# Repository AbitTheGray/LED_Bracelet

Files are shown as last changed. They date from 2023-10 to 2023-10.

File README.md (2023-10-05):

# LED Bracelet

Single-cell LED Bracelet controlled by ESP32-C3.

While the bracelet/collar can work in "standalone" mode, it is recommended to connect it to other device using [BLE](https://en.wikipedia.org/wiki/Bluetooth_Low_Energy).

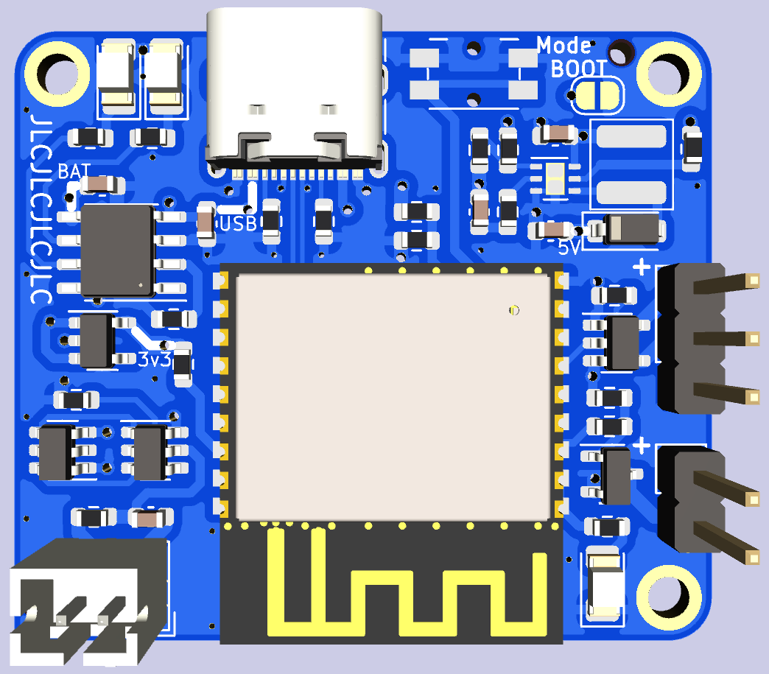
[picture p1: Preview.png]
PCB Preview


**This board is untested.**

Designed to be manufactured by [JLCPCB](https://jlcpcb.com/) as 4layer PCB with both inner layers acting as GND (you can probably use just the outer layers).

Requires [Espressif's KiCad Libraries](https://github.com/espressif/kicad-libraries).

## Features

- 5V LED strip
  - Designed for `WS2812` LEDs (=digital signal)
- 5V LED filament (outline)
  - Most of those filaments are 3V so use two of them, 2.5V should be enough
  - Can use PWM for brightness control
- USB-C charging
  - 5V 1.5A max (5.1k resistors)
  - `TP4056` charger
    - Status LEDs
      - Red = Charging
      - Blue = Standby
    - 1S 1A charging (1 cell in series, unlimited in parallel)
  - 1.5A discharge (`DW01A`)
  - Voltage measurement
    - 3/4 of voltage
    - Max 4.4V (=don't connect to 5V / USB)
- ESP32-C3 controller
  - BLE controls
  - Mode button to cycle colors
  - BOOT jumper pads (instead of a button)

### Warnings

- There are no reverse-polarity protections
- There are no fuses, you are responsible for maximum current on 5V output(s)
  - 1.2A shared between LED Strip and LED Filament connectors
    - max 20 RGB LEDs as `20*3*20mA = 1.2A` (`3` as the current is for each LED of RGB)
- Highlighted traces on silkscreen show voltages to measure (for testing)
- Some components are not in component placement
  - Use any `1206` LEDs (recommended colors are on silkscreen)
  - Mode button may need an uncommon component
  - Any THT connectors (battery + pin headers)
- Some components may need rotation tweak for fabrication
  - All `U` and `Q` components may need a rotation change (align 1st pin with long line on silkscreen)
  - `L1` needs 90deg rotation

### Possible future features

- Gyro+accelerometer to measure hand movement (available through BLE)
- Dedicated BLE button (BOOT button?) + status LED

## TODO

- Implement logic for `BLUETOOTH_ON_NO_CLIENT_WAIT`
  - Wait X seconds after turning the BLE ON, then turn it OFF if no client connected in the meantime
- Turn bluetooth OFF on critical battery level (and prevent it from turning on)
  - Compile define to disable this behavior
  - Add "What happens on Battery Critical?" section to [FAQ](FAQ.md)
- Compile define to independently disable Deep Sleep

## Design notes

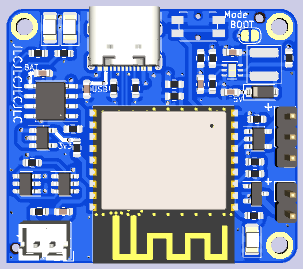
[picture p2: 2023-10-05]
PreviewSmall.png

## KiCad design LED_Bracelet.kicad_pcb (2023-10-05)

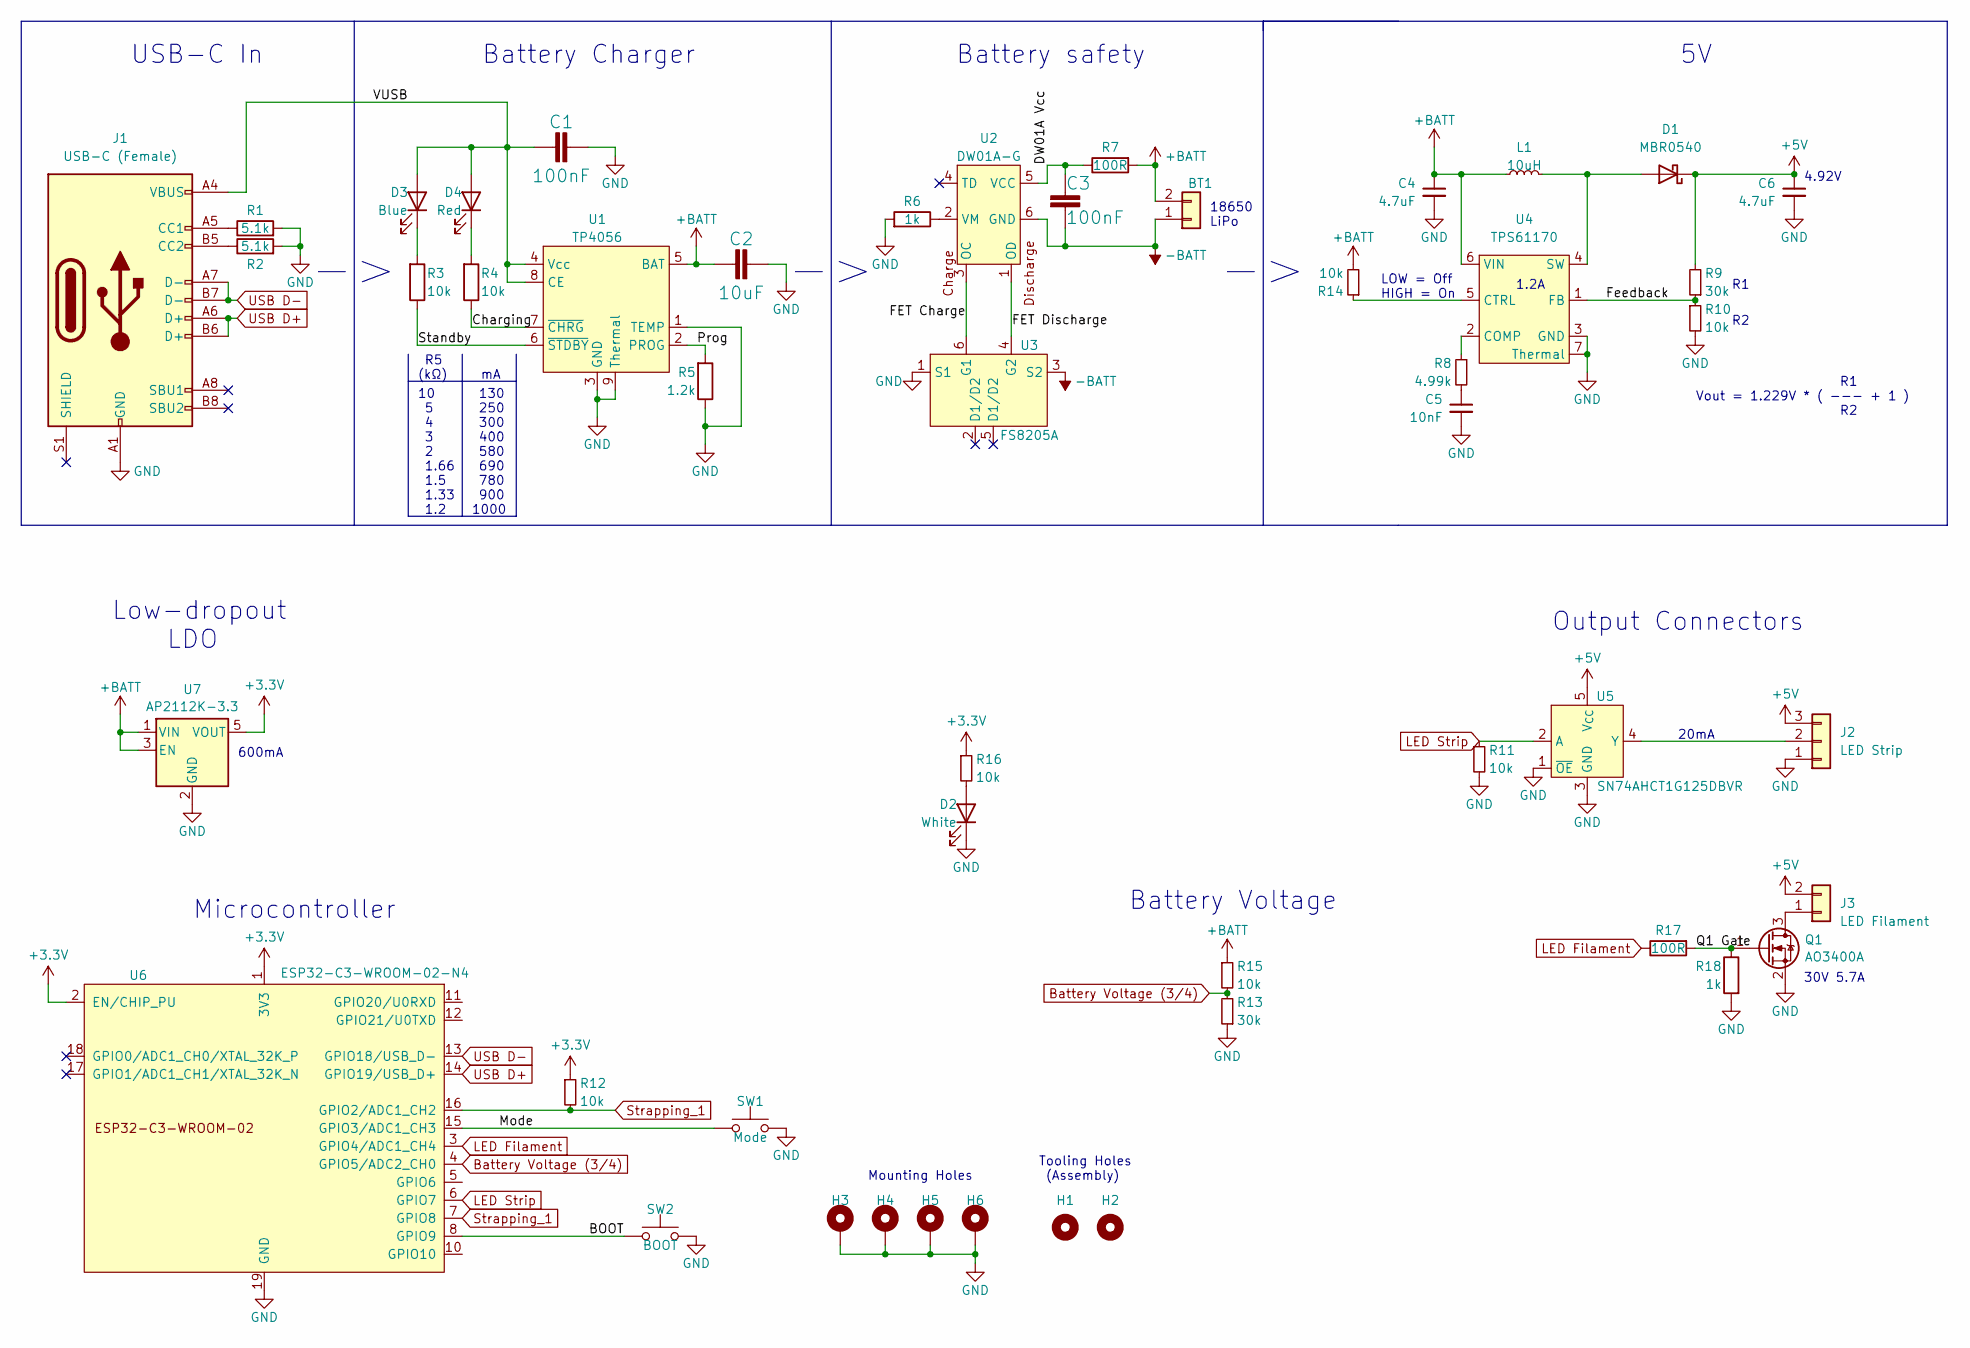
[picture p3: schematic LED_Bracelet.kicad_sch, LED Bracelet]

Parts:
BT1: Conn_01x02; JST_PH_B2B-PH-K_1x02_P2.00mm_Vertical
C1, C3: 100nF; C_0603_1608Metric; LCSC C14663
C2: 10uF; C_0603_1608Metric; LCSC C96446
C4, C6: 4.7uF; C_0603_1608Metric; LCSC C19666
C5: 10nF; C_0603_1608Metric; LCSC C57112
D1: MBR0540; D_SOD-123; LCSC C116159
D2: White; LED_1206_3216Metric
D3: Blue; LED_1206_3216Metric
D4: Red; LED_1206_3216Metric
H1, H2: MountingHole_Pad; JLCPCB ToolingHole
H3, H4, H5, H6: MountingHole_Pad; MountingHole_2.2mm_M2_ISO7380_Pad
J1: USB-C (Female); USB_C_Receptacle_GCT_USB4105-xx-A_16P_TopMnt_Horizontal; LCSC C2765186
J2: LED Strip; PinHeader_1x03_P2.54mm_Vertical
J3: LED Filament; PinHeader_1x02_P2.54mm_Vertical
L1: 10uH; Inductor 4x4; LCSC C497803
Q1: AO3400A; SOT-23; LCSC C20917
R1, R2: 5.1k; R_0603_1608Metric; LCSC C23186
R3, R4, R10, R11, R12, R14, R15, R16: 10k; R_0603_1608Metric; LCSC C25804
R5: 1.2k; R_0603_1608Metric; LCSC C22765
R6, R18: 1k; R_0603_1608Metric; LCSC C21190
R7, R17: 100R; R_0603_1608Metric; LCSC C22775
R8: 4.99k; R_0603_1608Metric; LCSC C2988946
R9, R13: 30k; R_0603_1608Metric; LCSC C22984
SW1: Mode; Panasonic_EVQPUL_EVQPUC
SW2: BOOT; SolderJumper-2_P1.3mm_Open_RoundedPad1.0x1.5mm
U1: TP4056; HSOP-8-1EP_3.9x4.9mm_P1.27mm_EP2.41x3.1mm_ThermalVias; LCSC C16581
U2: DW01A-G; SOT-23-6; LCSC C351410
U3: FS8205A; SOT-23-6; LCSC C908265
U4: TPS61170; DFN-6-1EP_2x2mm_P0.65mm_EP1.01x1.7mm; LCSC C15163
U5: SN74AHCT1G125DBVR; SOT-23-5; LCSC C7484
U6: ESP32-C3-WROOM-02-N4; ESP32-C3-WROOM-02; LCSC C2934560
U7: AP2112K-3.3; SOT-23-5; LCSC C51118

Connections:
+3.3V: R12.1, R16.1, U6.1 (3V3), U6.2 (EN/CHIP_PU), U7.5 (VOUT)
+5V: C6.1, D1.1 (K), J2.3, J3.2, R9.2, U5.5 (V_{CC})
+BATT: BT1.2, C2.1, C4.1, L1.1, R7.2, R14.2, R15.1, U1.5 (BAT), U4.6 (VIN), U7.1 (VIN), U7.3 (EN)
-BATT: BT1.1, C3.2, U2.6 (GND), U3.3 (S2)
/BOOT: SW2.2, U6.8 (GPIO9)
/Charging: R4.1, U1.7 (~CHRG)
/DW01A Vcc: C3.1, R7.1, U2.5 (VCC)
/FET Charge: U2.3 (OC), U3.6 (G1)
/FET Discharge: U2.1 (OD), U3.4 (G2)
/Feedback: R9.1, R10.1, U4.1 (FB)
/Mode: SW1.2, U6.15 (GPIO3/ADC1_CH3)
/Prog: R5.2, U1.2 (PROG)
/Q1 Gate: Q1.1 (G), R17.2, R18.1
/Standby: R3.1, U1.6 (~STDBY)
/VUSB: C1.1, D3.2 (A), D4.2 (A), J1.A4 (VBUS), J1.A9 (VBUS), J1.B4 (VBUS), J1.B9 (VBUS), U1.4 (Vcc), U1.8 (CE)
Battery Voltage (3/4): R13.2, R15.2, U6.4 (GPIO5/ADC2_CH0)
GND: C1.2, C2.2, C4.2, C5.2, C6.2, D2.1 (K), H3.1, H4.1, H5.1, H6.1, J1.A1 (GND), J1.A12 (GND), J1.B1 (GND), J1.B12 (GND), J2.1, Q1.2 (S), R1.2, R2.2, R5.1, R6.2, R10.2, R11.2, R13.1, R18.2, SW1.1, SW2.1, U1.1 (TEMP), U1.3 (GND), U1.9 (Thermal), U3.1 (S1), U4.3 (GND), U4.7 (Thermal), U5.1 (~OE), U5.3 (GND), U6.9 (GND), U6.19 (GND), U7.2 (GND)
LED Filament: R17.1, U6.3 (GPIO4/ADC1_CH4)
LED Strip: R11.1, U5.2 (A), U6.6 (GPIO7)
unnamed: C5.1, R8.2
unnamed: D1.2 (A), L1.2, U4.4 (SW)
unnamed: D2.2 (A), R16.2
unnamed: D3.1 (K), R3.2
unnamed: D4.1 (K), R4.2
unnamed: J1.A5 (CC1), R1.1
unnamed: J1.B5 (CC2), R2.1
unnamed: J2.2, U5.4 (Y)
unnamed: J3.1, Q1.3 (D)
unnamed: R6.1, U2.2 (VM)
unnamed: R8.1, U4.2 (COMP)
unnamed: R14.1, U4.5 (CTRL)
Strapping_1: R12.2, U6.7 (GPIO8), U6.16 (GPIO2/ADC1_CH2)
USB D+: J1.A6 (D+), J1.B6 (D+), U6.14 (GPIO19/USB_D+)
USB D-: J1.A7 (D-), J1.B7 (D-), U6.13 (GPIO18/USB_D-)

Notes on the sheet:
20mA
130 250 300 400 580 690 780 900 1000
Microcontroller
18650 LiPo
USB-C In
R5 (kΩ)
Tooling Holes (Assembly)
Low-dropout LDO
600mA
10 5 4 3 2 1.66 1.5 1.33 1.2
Output Connectors
Battery Charger
R1 Vout = 1.229V * ( --- + 1 ) R2
1.2A
30V 5.7A
Battery safety
Battery Voltage
Mounting Holes
LOW = Off HIGH = On
4.92V

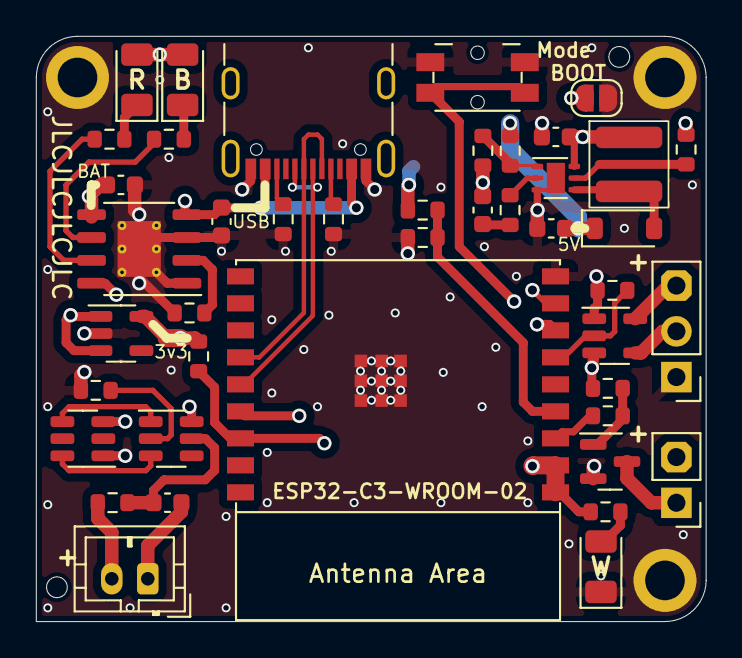
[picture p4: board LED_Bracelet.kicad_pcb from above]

Board: 4 copper layers, 37.2 x 32.5 mm, 48 parts (0 on the bottom side), 34 nets.

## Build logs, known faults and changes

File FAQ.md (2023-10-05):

# Frequently Asked Questions

## How many LEDs can I connect as an LED Strip?

There is 1.2A limit on 5V boost converter which is shared between LED Strip and LED Filament connectors.
If you leave LED Filament empty and have 60mA total RGB LED (like `WS2812`), you can have only 20 LEDs running at full brightness white color at the same time.

## Which LED Strips can I use?

The LED Strip connector (3pin) is designed for indexable 5V LED strips of `WS2812` but any other 1-wire 5V LEDs should work.
Don't use LED Strips of other voltages (like 12V).

If you have fixed-color LED Strips, you can use LED Filament connector (2pin) and control them using a PWM signal.

Always check maximum current!

## Why are Mode and BOOT buttons separated?

This is due to Mode button being used to wake up from sleep which is possible only on `GPIO0` - `GPIO5` but BOOT button must be on `GPIO9`.
It could also be a problem with Boot Mode switching on waking up from sleep (maybe, not tested).

## Why isn't BOOT a real button?

There is not enough space.
Even with shifted components, there is not enough space for 2 buttons.
They cannot be close to each other to prevent users from mixing them up.
BOOT button cannot be "hidden" or have different orientation as it can cause hard-to-figure-out problems when pressed by its environment.

## Can I enable/disable Bluetooth support?

Yes.

In fact, there are several options you can easily tweak.
In `platformio.ini` there are `build_flags` which you can comment-out using `;` at the beginning of the line.

| Flag | Recommended | Effect |
|---|:---:|---|
| `DEBUG` | OFF | Enables `Serial` output (default speed `115200`, `SERIAL_SPEED`). |
| `TIMER_LOOP` | ON | Uses timer for checking several things (like battery voltage, possibility of sleep...). |
| `BLE_INTERFACE_ENABLE` | ON | Enables Bluetooth support. Mode button will act slightly different when Bluetooth is disabled by this. |
| `CONFIG_PM_ENABLE` | ON | Enables ESP Power Management (variable CPU frequency) and allows it to enter (deep) sleep. |
| `CONFIG_CPU_MIN_FREQ`  | 40 | Minimum dynamic frequency, requires `CONFIG_PM_ENABLE` to work. |
| `CONFIG_CPU_MAX_FREQ`  | 160 | Maximum dynamic frequency, requires `CONFIG_PM_ENABLE` to work. |

Do not comment out `CONFIG_FREERTOS_USE_TICKLESS_IDLE` and `CONFIG_FREERTOS_IDLE_TIME_BEFORE_SLEEP`, those do not have an effect without `CONFIG_PM_ENABLE` if you really need them OFF.

## How do I change Bluetooth name/passkey?

Both name and passkey (or password) are hard-coded in the software.
To change them you need to alter `BLE_NAME` and `BLE_PASSKEY` values in `config.hpp`.
If you do not want to have any passkey (not recommended) use value `0`.

You need to recompile the software.
Make sure you have Bluetooth enabled when compiling.

## Can I change BLE Service/Characteristic UUID?

Yes.

Look at the beginning of `ble.cpp` file.
Battery service+characteristics are from official Bluetooth GATT, the rest is random v4 UUIDs (per-service) first manually defined first part (4 bytes) of the UUID.

## Can I use any ESP microprocessor?

No.

Both the PCB and software are made for `ESP32-C3`.
`ESP32-C3-WROOM-02` for the PCB to be more specific (and its `ESP32-C3-WROOM-02U` variant with an external antenna).

In case you would like to port this project, you would need to:
- Change PCB or create WROOM-compatible daughter board
- Change `PIN_`* defines in `config.hpp`
- Check Mode Button initiation (`setup()` in `main.cpp`) as you need a button there which can wake up the ESP from deep sleep (there is ESP32-S3 specific check)

## Which battery should I use?

The PCB is designed for any Li-Ion battery (up to 4.25V, chargeable by `TP4056`) which can provide at least 2A (lower in theory if you have less LEDs).
See "Maximum discharge current" in your battery's specification.

## Which LED strips are supported on the connector?

The PCB and software are designed for `WS2812` / `WS2812B` LEDs.
Other protocol-compatible LEDs should work.

Maximum supported LEDs is 20 (due to current limit, constant `STRIP_LED_COUNT` in `config.hpp`).
Decreasing this count may allow you to change colors a little bit faster (not needed at all).

Do not increase `STRIP_LED_COUNT` unless you really know what you are doing as you will go over maximum current.
If you must, you should either use only one RGB component (red, green or blue) or modify `STRIP_LED_BRIGHTNESS` to limit maximum current.

## How do I change colors/brightness modes?

Filament brightnesses are defined in `filamentBrightnesses` array with `FILAMENT_BRIGHTNESSES` entries.
LED Strip colors are defined in `stripColors` array with `STRIP_COLORS` entries.

Both arrays have values defined in `config.cpp`.
There is no "black"/OFF value in those arrays, index `-1` is used instead (and hard-coded).

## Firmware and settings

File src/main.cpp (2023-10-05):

#include <esp_pm.h>
#include "config.hpp"

#ifdef TIMER_LOOP
#   include "ESP32_C3_TimerInterrupt.h"
#endif

#ifdef BLE_INTERFACE_ENABLE
extern BLECharacteristic* bleCharBatteryPercentage;
extern BLECharacteristic* bleCharBatteryCritical;

extern BLECharacteristic* bleCharButtonsBoot;

extern BLECharacteristic* bleCharEspCoreTemp;
#endif

#ifdef TIMER_LOOP
ESP32Timer Timer0(0);
bool IRAM_ATTR TimerHandler0(void* timerNo);
#endif

void setup()
{
#ifdef DEBUG
    Serial.begin(SERIAL_SPEED);
    do
    {
        delay(100);
    }
    while(!Serial && millis() < 5000);
#endif

    // LED Filament (PWM)
    {
        analogWriteResolution(8); // 256 values
        pinMode(PIN_FILAMENT_PWM, OUTPUT);

        // Turn OFF
        setFilamentBrightness(static_cast<uint8_t>(0));
    }

    // LED Strip
    {
        strip.setBrightness(STRIP_LED_BRIGHTNESS);

        // Turn OFF
        strip.setAllLedsColor(0);
        stripOffStartTime = millis();
    }

    // Battery Voltage (analog)
    {
        analogReadResolution(8);
        pinMode(PIN_BATTERY_VOLTAGE, ANALOG /* INPUT */);
    }

    // Mode Button
    {
        pinMode(PIN_BUTTON_MODE, INPUT_PULLUP);
        attachInterrupt(PIN_BUTTON_MODE, buttonPressInterrupt, FALLING);
        attachInterrupt(PIN_BUTTON_MODE, buttonReleaseInterrupt, RISING);

#ifdef CONFIG_PM_ENABLE
        // Sleep wakeup on button press
        gpio_wakeup_enable(static_cast<gpio_num_t>(PIN_BUTTON_MODE), GPIO_INTR_LOW_LEVEL);
        esp_sleep_enable_gpio_wakeup();
#   if PIN_BUTTON_MODE <= 5 // Required for Deep sleep
        esp_deep_sleep_enable_gpio_wakeup(1u << PIN_BUTTON_MODE, ESP_GPIO_WAKEUP_GPIO_LOW);
#   else
#       warning "Mode button won't wakeup the microcontroller from deep sleep"
#   endif
        esp_sleep_pd_config(ESP_PD_DOMAIN_VDDSDIO, ESP_PD_OPTION_ON);//TODO Is needed?
#endif
    }

    // Boot button
    {
        pinMode(PIN_BUTTON_BOOT, INPUT_PULLUP);
#ifdef BLE_INTERFACE_ENABLE
        attachInterrupt(
            PIN_BUTTON_BOOT,
            []()
            {
                if(bleCharButtonsBoot)
                {
                    bleCharButtonsBoot->setValue(static_cast<uint8_t>(1));
                    bleCharButtonsBoot->notify();
                }
            },
            FALLING
        );
        attachInterrupt(
            PIN_BUTTON_BOOT,
            []()
            {
                if(bleCharButtonsBoot)
                {
                    bleCharButtonsBoot->setValue(static_cast<uint8_t>(0));
                    bleCharButtonsBoot->notify(); //THINK Do we want 2nd notify?
                }
            },
            RISING
        );
#endif
    }

    // Sleep
    {
#ifdef CONFIG_PM_ENABLE
        esp_pm_config_esp32c3_t pm_config = {
#   ifdef CONFIG_CPU_MAX_FREQ
            .max_freq_mhz = CONFIG_CPU_MAX_FREQ,
#   else
            .max_freq_mhz = 160,
#   endif
#   ifdef CONFIG_CPU_MIN_FREQ
            .min_freq_mhz = CONFIG_CPU_MIN_FREQ,
#   else
            .min_freq_mhz = 10,
#   endif
#   if CONFIG_FREERTOS_USE_TICKLESS_IDLE
            .light_sleep_enable = true
#   endif
        };
        esp_pm_configure(&pm_config);
#endif

#ifdef TIMER_LOOP
        if (Timer0.attachInterruptInterval(TICK_FREQUENCY_MS * 1000, TimerHandler0))
        {
            DEBUG_PRINT(F("Starting  ITimer0 OK, millis() = "));
            DEBUG_PRINTLN(millis());
        }
        else
        {
            DEBUG_PRINTLN(F("Can't set ITimer0. Select another freq. or timer"));
        }
#endif
    }

    DEBUG_PRINTLN(F("setup() finished"));
}
void IRAM_ATTR tick()
{
    auto currentTime = millis();

    // Bluetooth turn off
    {
#ifdef BLE_INTERFACE_ENABLE
        if(turnBluetoothOffAfterTime >= currentTime && isBluetoothOn())
        {
            deinitBluetooth();
        }
#endif
    }

    // Battery
    {
#ifdef BLE_INTERFACE_ENABLE
        auto batteryVoltage = getBatteryVoltage();
        auto batteryPercentage = guessBatteryPercentage(batteryVoltage);

        if(bleCharBatteryPercentage)
        {
            bleCharBatteryPercentage->setValue(static_cast<uint8_t>(batteryPercentage));
        }
        if(bleCharBatteryCritical)
        {
            uint8_t batteryCritical = batteryPercentage <= BATTERY_CRITICAL_PERCENTAGE ? 1 : 0;
            auto wasBatteryCriticalValue = bleCharBatteryCritical->getValue();
            uint8_t wasBatteryCritical = wasBatteryCriticalValue.size() == 0 ? 0 : wasBatteryCriticalValue[0];

            bleCharBatteryCritical->setValue(static_cast<uint8_t>(batteryCritical));
            if(wasBatteryCritical != batteryCritical)
            {
                bleCharBatteryCritical->notify();

#ifdef DEBUG
                if(batteryCritical)
                {
                    DEBUG_PRINTLN(F("Battery became critical"));
                }
                else
                {
                    DEBUG_PRINTLN(F("Battery no longer critical"));
                }
#endif
            }
        }
#endif
    }

    // Core temperature
    {
#ifdef BLE_INTERFACE_ENABLE
        if(bleCharEspCoreTemp)
        {
            bleCharEspCoreTemp->setValue(temperatureRead());
        }
#endif
    }

    // Sleep
    {
#ifdef CONFIG_PM_ENABLE
        if(canEnterDeepSleep())
        {
            DEBUG_PRINTLN(F("Entering deep sleep..."));
            esp_deep_sleep_start();
        }
#endif
    }
}
#ifdef TIMER_LOOP
bool IRAM_ATTR TimerHandler0(void* timerNo)
{
    tick();

    return true;
}
#endif
void loop()
{
#ifndef TIMER_LOOP
    tick();
    delay(LOOP_CHECK_DELAY_MS);
#endif
}

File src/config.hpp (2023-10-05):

#pragma once
#include <Arduino.h>

#define SERIAL_SPEED 115200
#ifdef DEBUG
#   define DEBUG_PRINT(a_msg) Serial.print(a_msg)
#   define DEBUG_PRINTLN(a_msg) Serial.println(a_msg)
#else
#   define DEBUG_PRINT(a_msg)
#   define DEBUG_PRINTLN(a_msg)
#endif

/// Checks prerequisites to enter deep sleep.
/// In addition to this make sure the IC is idle for some time so it does not fall asleep between button presses.
bool canEnterDeepSleep();
/// Number of milliseconds to wait before going into deep sleep when all outputs are OFF.
#define OUTPUT_OFF_SLEEP_TIME (1000 * 60) /* 1 minute */
/// Frequency of ticks tor repeated logic.
#define TICK_FREQUENCY_MS (1000 * 1) /* 1s */

#define PIN_FILAMENT_PWM 4
#define FILAMENT_BRIGHTNESSES 2
extern const uint8_t filamentBrightnesses[FILAMENT_BRIGHTNESSES];
/// Index into `filamentBrightnesses`.
/// Can be `-1` for OFF.
extern int filamentMode;
/// Start time when LED Filament was turned OFF.
/// Ignored when Bluetooth is connected.
/// Add OUTPUT_OFF_SLEEP_TIME to this value when comparing.
extern unsigned long filamentOffStartTime;
/// Set filament brightness.
/// 0 = OFF
/// 255 = ON
void setFilamentBrightness(uint8_t value255);
/// Set filament brightness.
/// Use value in range <0,1>.
inline void setFilamentBrightness(float value01) { setFilamentBrightness(static_cast<uint8_t>(value01 * 255u)); }

#include "Freenove_WS2812_Lib_for_ESP32.h"
#define STRIP_LED_COUNT 20
#define STRIP_LED_BRIGHTNESS 0xFF /* 100% (values in `stripColors` represent actual colors) */
#define PIN_STRIP_DIGITAL 7
extern Freenove_ESP32_WS2812 strip;
#define STRIP_COLORS 8
/// Colors to cycle through using Mode button
extern const uint32_t stripColors[STRIP_COLORS];
/// Index into `stripColors`.
/// Can be `-1` for OFF.
extern int stripMode;
/// Start time when LED Strip was fully turned OFF.
/// Ignored when Bluetooth is connected.
/// Add OUTPUT_OFF_SLEEP_TIME to this value when comparing.
extern unsigned long stripOffStartTime;

#define PIN_BATTERY_VOLTAGE 5 /* 3/4 of real voltage */
/// Reads analog battery voltage.
/// Returns value between 0 and 4.4V.
float getBatteryVoltage();
/// Rough guess of battery percentage from its voltage.
/// Not accurate at all but enough for this purpose.
uint8_t guessBatteryPercentage(float voltage);
/// Minimum battery voltage, equivalent to 0%.
#define BATTERY_VOLTAGE_MIN 3.5f
/// Maximum battery voltage, equivalent to 100%.
#define BATTERY_VOLTAGE_MAX 4.2f
/// Battery will be considered at "Critical Low" when percentage reaches below this value.
#define BATTERY_CRITICAL_PERCENTAGE 15

#define PIN_BUTTON_BOOT 9 /* Ground = Pressed */

#define PIN_BUTTON_MODE 3 /* Ground = Pressed */


#ifdef BLE_INTERFACE_ENABLE
#   include "NimBLEDevice.h"
/// Initialize Bluetooth and allow devices to connect.
void initBluetooth();
/// Disconnect all devices and disable Bluetooth.
void deinitBluetooth();
/// Retruns true if Bluetooth is currently enabled and initialized.
inline bool isBluetoothOn() { return BLEDevice::getInitialized(); }
/// Retruns true if Bluetooth is currently enabled, initialized and there is any device connected to it.
inline bool isBluetoothConnected() { return BLEDevice::getInitialized() && BLEDevice::getClientListSize() > 0; }
/// Bluetooth Device name.
#   define BLE_NAME "LED Bracelet"
/// Passkey to connect using Bluetooth.
/// Change to 0 to disable.
#   define BLE_PASSKEY 8018
/// How long to wait for clients before turning Bluetooth OFF.
#   define BLUETOOTH_ON_NO_CLIENT_WAIT 60 /* seconds */
/// Time in milliseconds.
/// If not 0 the nBluetooth should be turned off after this time is reached.
extern unsigned long turnBluetoothOffAfterTime;
#else
inline void initBluetooth() {}
inline void deinitBluetooth() {}
inline bool isBluetoothConnected() { return false; }
#endif

/// Internal function.
/// Called when Mode button is pressed.
/// Don't put any logic there, use `onButtonPress` which identifies short and long press (and discards invalid presses).
void buttonPressInterrupt();
/// Internal function.
/// Called when Mode button is pressed.
/// Don't put any logic there, use `onButtonPress` which identifies short and long press (and discards invalid presses).
void buttonReleaseInterrupt();
/// Mode button function:
/// - Bluetooth connected or ON:
///   - Short press: Notify BLE characteristic
///   - Long press: Disconnect and turn OFF Bluetooth
/// - Bluetooth off:
///   - Short press: Cycle between LED strip colors with 3 sets of strip brightness (first all modes with strip off, then all modes 100%, then all modes at 100%)
///     - For colors see `stripColors`, for filament values see `filamentBrightnesses`
///   - Long press: Turn Bluetooth ON
void onButtonPress(bool longPress);

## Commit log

2023-09-29 Complete schematic, position components on the PCB
    [LED_Bracelet.kicad_pcb, LED_Bracelet.kicad_sch]
2023-10-01 Tweaks to the PCB
    [LED_Bracelet.kicad_pcb, LED_Bracelet.kicad_sch]
2023-10-05 First software version + some PCB changes Separate BOOT and Mode buttons. LED Filament MOSFET (Q1) has pulldown resistor and is the correct channel. PlatformIO project + code. Frequently Asked Questi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
    [LED_Bracelet.kicad_pcb, LED_Bracelet.kicad_sch]
